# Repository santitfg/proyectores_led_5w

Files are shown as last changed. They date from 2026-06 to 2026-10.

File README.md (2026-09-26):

# redo
en el 74hc595 el pin 10 (rst ) si o si a vcc
y el pin 13 output enable va a gng si o si 

### Conector 1 — entrada de datos serie (SER)

Chip: 74HC595 (registro de desplazamiento serie-in / paralelo-out). Molex 5 pines.

| Pin | Color | Señal | GPIO ESP32 | GPIO ESP32-S3 | Descripción |
|-----|---|---|---|---|---|
| 1 | ⚫ Negro  | GND | — | — | Tierra |
| 2 | ⚪ Blanco | SRCLK / CP | `gpio23` | `gpio18` | Shift Clock (SH_CP, pin 11) / SPI2 SCLK |
| 3 | 🟢 Verde  | RCLK / PL | `gpio22` | `gpio10` | Register Clock / Latch (ST_CP, pin 12) |
| 4 | 🩶 Gris | SER  / DS | `gpio2` | `gpio4` | Serial data in (DS, pin 14) / SPI2 MOSI |
| 5 | 🔴 Rojo | VCC | — | — | Alimentación |

### Conector 2 — salida en cascada (Q7)

Conector para encadenar el `SER` (pin 14) del siguiente 74HC595 a la salida en cascada `Q7'` (pin 9) de este.

| Pin | Color | Señal | GPIO ESP32 | GPIO ESP32-S3 | Descripción |
|-----|---|---|---|---|---|
| 1 | ⚫ Negro  | GND | — | — | Tierra |
| 2 | ⚪ Blanco | SRCLK  / CP| `gpio23` | `gpio18` | Shift Clock (SH_CP, pin 11) / SPI2 SCLK |
| 3 | 🟢 Verde  | RCLK  / PL | `gpio22` | `gpio10` | Register Clock / Latch (ST_CP, pin 12) |
| 4 | 🩶 Gris | Q7 | `gpio35` | `gpio5` | Salida en cascada (Q7', pin 9) hacia el `SER` del siguiente 74HC595 |
| 5 | 🔴 Rojo | VCC | — | — | Alimentación |

estoy controlando con el 74hc595 la matriz desde las siguientes filas y columnas:
Q0 ... Q3 se conectan a los 2n2222 controlanto el gate de IRF9630
Q4 ... Q7 se conectan directo al gate IRLZ44N

# revision de laburo

PCB

IRF9630 high side y esta a up down en gate
IRLZ44N	low side y esta a pull down en gate

————

revision en protoboard 5v y señales activas de irlz44n y 2n2222 a 3.3:
IRLZ44N
gate ( pin 1) 10k a pull Down 1k a señal (vcc activa el paso de corriente)
drain ( pin 2) a gnd-terminal
source (pin 3) a GND

IRF9630
gate ( pin 1) 10k a pull up 1k a señal (gnd activa el paso de corriente)(2n2222)
drain ( pin 2) a Vout-terminal
source (pin 3) a VIN

2n2222 ( funcionamiento real es emisor a gnd y colector lado vcc)
emisor (pin 1) a GND
base (pin 2) señal ic ( via 1k Resi)
colector (pin 3) ( señal hacia irf9630 via 1k resi) vcc activa el paso de corriente)x

TODO: arreglar kicad corrigiendo los elementos mencionados (inverti pista VIN x Vout-terminal)

Fallas en el circuito funciona la mitad de puntos en modo damero
O X O X
X O X O 
O X O X
X O X O

Nomenclar correstamente las columnas y filas 
pero los v y gnd en los mismos no todos fallan de la misma manera
1: 2: 3: 4: 

Filas
q0 (pin 15) : IRF9630 1
q1 (pin 1) : IRF9630 2
q2 (pin 2) : IRF9630 3
q3 (pin 3) : IRF9630 4

Columnas
q4 (pin 4) : IRLZ44N 1
q5 (pin 5) : IRLZ44N 2
q6 (pin 6) : IRLZ44N 3
q7 (pin 7) : IRLZ44N 4

.   q4  q3  q2  q1
q3  4   3   2   1
q2  8   7   6   5
q1  12  11  10  9
q0  16  15  14  13     

funciona raro al enviar 0xFF se apagan las salidas y al 0x00 se prenden

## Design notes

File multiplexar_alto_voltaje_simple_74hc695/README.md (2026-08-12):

# Multiplexado de Matriz LED con 74HC595

Control de una matriz de LEDs de alto voltaje mediante un registro de desplazamiento 74HC595,
con MOSFETs canal N (IRFZ44N) para columnas y canal P (IRF9630) para filas.

Actualmente configurado en **2×2**, escalable a **4×4** cambiando dos constantes.

---

## Hardware

### Componentes
| Componente | Función |
|---|---|
| Arduino (cualquier) | Microcontrolador |
| 74HC595 | Registro de desplazamiento (8 bits) |
| IRFZ44N × N_COLS | MOSFET canal N → columnas (lado bajo) |
| IRF9630 × N_ROWS | MOSFET canal P → filas (lado alto) |

### Conexión 74HC595

| Arduino | Pin 74HC595 | Señal |
|---|---|---|
| D11 | 14 (DS) | Serial data |
| D13 | 11 (SCLK) | Shift clock |
| D10 | 12 (RCLK) | Latch / storage clock |
| VCC | 16 (VCC) | Alimentación |
| GND | 8 (GND) | Tierra |
| GND | 13 (OE) | Output enable (activo bajo) |
| VCC | 10 (SRCLR) | Clear (activo bajo, mantener HIGH) |

Las salidas Q0–Q(N_COLS-1) van a las compuertas de los IRFZ44N (columnas)
y Q(N_COLS)–Q(N_COLS+N_ROWS-1) van a las compuertas de los IRF9630 (filas).

---

## Bit layout del registro

```
2×2:  bit3  bit2  bit1  bit0
       r1    r0    c1    c0

4×4:  bit7  bit6  bit5  bit4  bit3  bit2  bit1  bit0
       r3    r2    r1    r0    c3    c2    c1    c0
```

- **Columnas (IRFZ44N canal N):** `1` = activo (MOSFET conduce)
- **Filas (IRF9630 canal P):** lógica `1` = activo, pero el firmware invierte automáticamente al enviar al 595 (`~rowMask`) porque el gate del P-channel requiere bajo para conducir

---

## Demo

El `loop()` habilita una compuerta más cada **200 ms** en orden acumulativo:

```
idx=0  c0           → col 0 habilitada
idx=1  c0 c1        → cols 0 y 1 habilitadas
idx=2  c0 c1 r0     → cols 0-1 + fila 0 habilitada
idx=3  c0 c1 r0 r1  → todo habilitado → reset
```

Salida Serial (115200 baud):
```
 0  | logic: 0000 0001  | phys: 0000 1101  | cols=0b1    rows=0b0
 1  | logic: 0000 0011  | phys: 0000 1111  | cols=0b11   rows=0b0
 2  | logic: 0000 0101  | phys: 0000 0101  | cols=0b1    rows=0b1
 3  | logic: 0000 0111  | phys: 0000 0111  | cols=0b11   rows=0b11
```
- **logic**: estado lógico (1 = activo, sin importar polaridad)
- **phys**: byte real enviado al 595 (filas invertidas para P-channel)

---

## Escalar a 4×4

Solo cambiar estas dos líneas en el sketch:

```cpp
const uint8_t N_COLS = 4;
const uint8_t N_ROWS = 4;
```

No hay más cambios necesarios. El cálculo de máscaras y el bit packing se adaptan automáticamente.

---

## Control individual de LEDs

```cpp
setLED(col, row, true);   // encender LED en columna col, fila row
setLED(col, row, false);  // apagar
```

> **Nota ghosting:** activar simultáneamente múltiples columnas y filas ilumina
> LEDs no deseados (ej: encender (c0,r0) y (c1,r1) también activa (c0,r1) y (c1,r0)).
> Ver la sección de multiplexing por fila al final del sketch para evitarlo.

---

## Multiplexing por fila (sin ghosting)

Para control de LEDs individuales sin ghosting, usar un framebuffer por fila:

```cpp
uint8_t framebuffer[N_ROWS] = { 0b01, 0b10 };  // fila0: col0 ON, fila1: col1 ON

for (uint8_t r = 0; r < N_ROWS; r++) {
    rowMask = (1 << r);
    colMask = framebuffer[r];
    sendToShiftReg();
    delayMicroseconds(500);   // tiempo de encendido por fila
    colMask = 0; rowMask = 0;
    sendToShiftReg();         // apagar entre filas evita ghosting
}
```

El ojo percibe todas las filas encendidas si el ciclo completo dura < ~20 ms.

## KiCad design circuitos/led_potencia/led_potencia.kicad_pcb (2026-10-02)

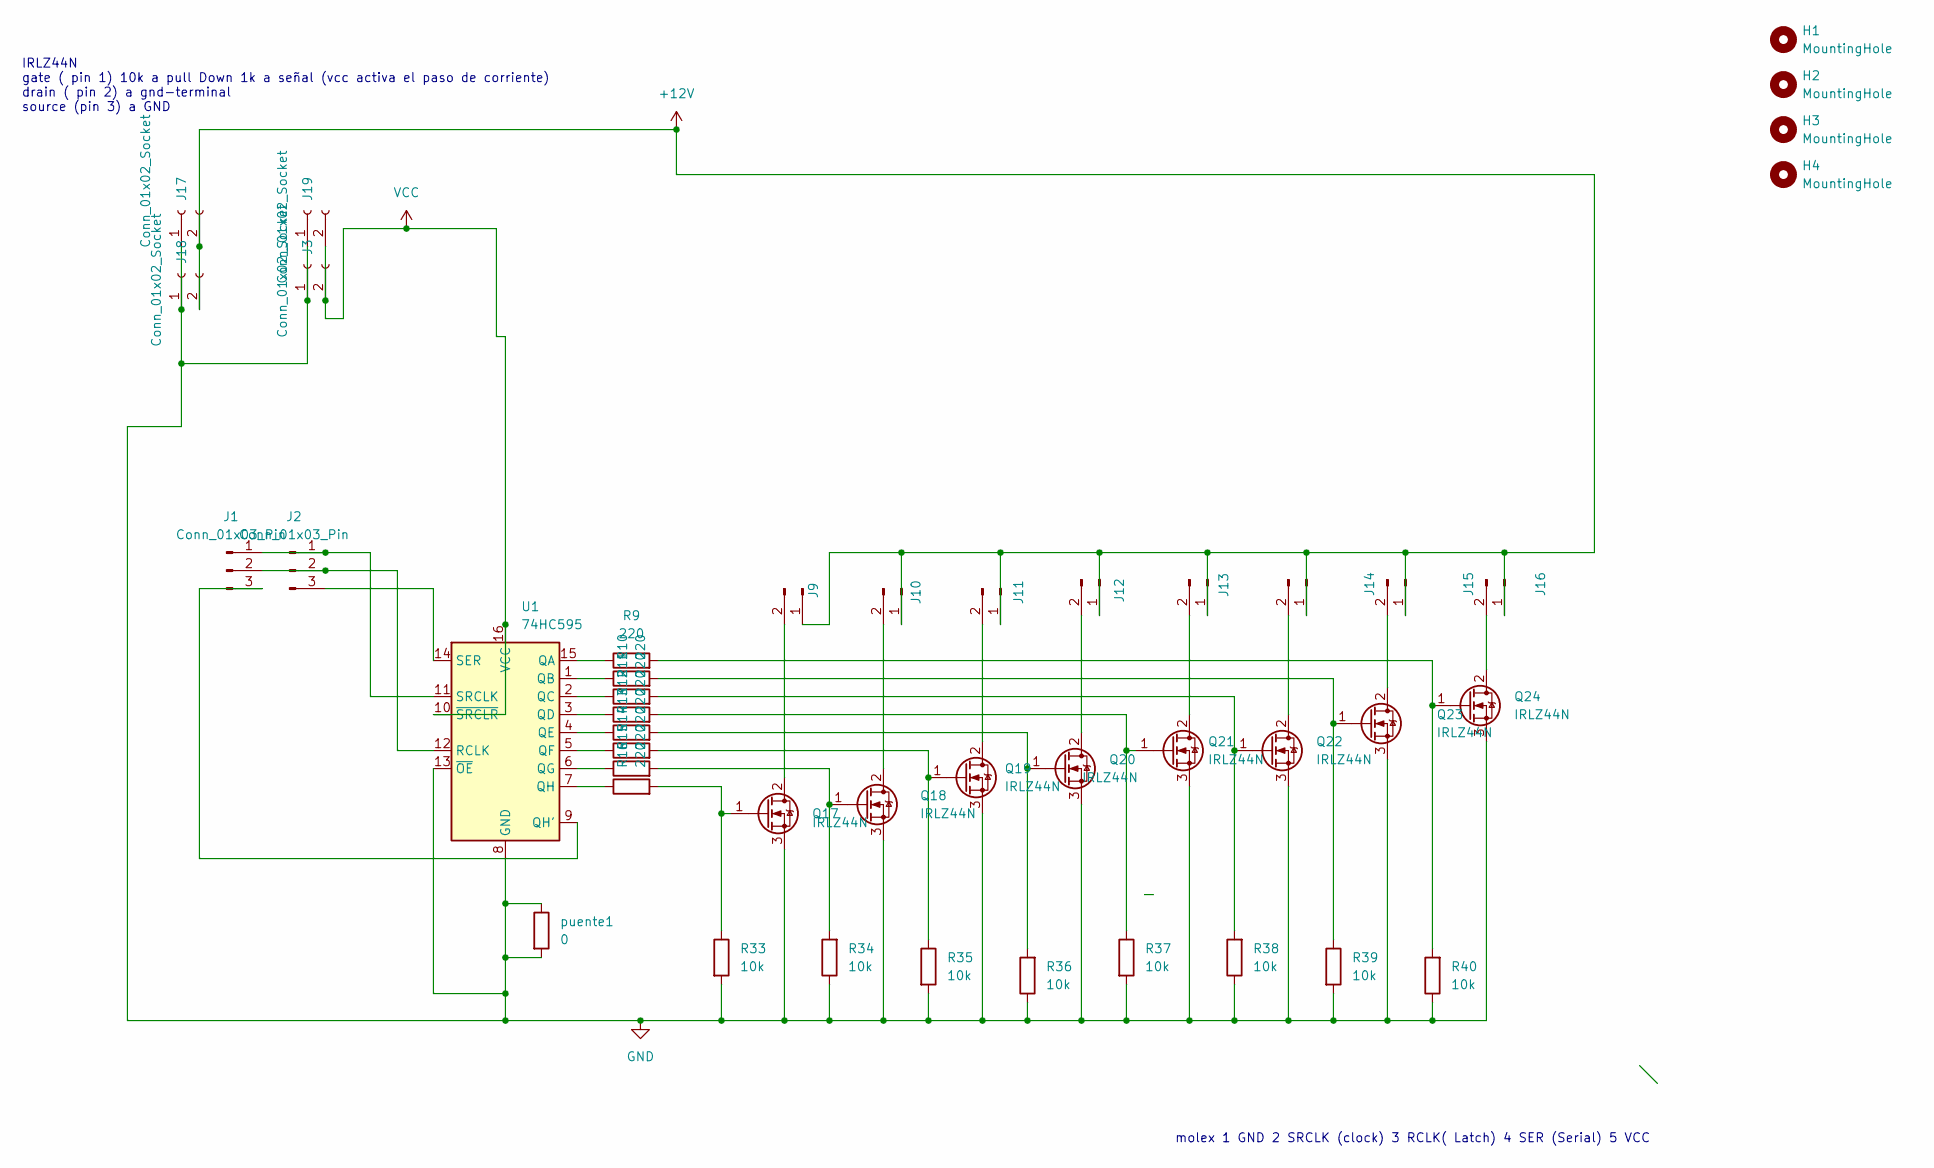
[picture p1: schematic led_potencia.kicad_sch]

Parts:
H1, H2, H3, H4: MountingHole; MountingHole_2.2mm_M2_DIN965_Pad
J1, J2: Conn_01x03_Pin; Molex_KK-254_AE-6410-03A_1x03_P2.54mm_Vertical
J3, J17, J18, J19: Conn_01x02_Socket; Molex_KK-254_AE-6410-02A_1x02_P2.54mm_Vertical
J9, J10, J11, J12, J13, J14, J15, J16: Conn_01x02_Pin; Molex_KK-254_AE-6410-02A_1x02_P2.54mm_Vertical
Q17, Q18, Q19, Q20, Q21, Q22, Q23, Q24: IRLZ44N; TO-220-3_Vertical
R9, R10, R11, R12, R13, R14, R15, R16: 220; R_Axial_DIN0204_L3.6mm_D1.6mm_P7.62mm_Horizontal
R33, R34, R35, R36, R37, R38, R39, R40: 10k; R_Axial_DIN0204_L3.6mm_D1.6mm_P7.62mm_Horizontal
U1: 74HC595; DIP-16_W7.62mm_Socket_LongPads
puente1: 0; R_Axial_DIN0204_L3.6mm_D1.6mm_P7.62mm_Horizontal

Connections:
+12V: J9.1, J10.1, J11.1, J12.1, J13.1, J14.1, J15.1, J16.1, J17.2, J18.2
GND: J3.1, J17.1, J18.1, J19.1, Q17.3 (S), Q18.3 (S), Q19.3 (S), Q20.3 (S), Q21.3 (S), Q22.3 (S), Q23.3 (S), Q24.3 (S), R33.2, R34.1, R35.2, R36.1, R37.2, R38.1, R39.2, R40.1, U1.8 (GND), U1.13 (~OE), puente1.1, puente1.2
unnamed: J1.1, J2.1, U1.11 (SRCLK)
unnamed: J1.2, J2.2, U1.12 (RCLK)
unnamed: J1.3, U1.9 (QH')
unnamed: J2.3, U1.14 (SER)
unnamed: J9.2, Q17.2 (D)
unnamed: J10.2, Q18.2 (D)
unnamed: J11.2, Q19.2 (D)
unnamed: J12.2, Q20.2 (D)
unnamed: J13.2, Q21.2 (D)
unnamed: J14.2, Q22.2 (D)
unnamed: J15.2, Q23.2 (D)
unnamed: J16.2, Q24.2 (D)
unnamed: Q17.1 (G), R16.2, R33.1
unnamed: Q18.1 (G), R15.2, R34.2
unnamed: Q19.1 (G), R14.2, R35.1
unnamed: Q20.1 (G), R13.2, R36.2
unnamed: Q21.1 (G), R12.2, R37.1
unnamed: Q22.1 (G), R11.2, R38.2
unnamed: Q23.1 (G), R10.2, R39.1
unnamed: Q24.1 (G), R9.2, R40.2
unnamed: R9.1, U1.15 (QA)
unnamed: R10.1, U1.1 (QB)
unnamed: R11.1, U1.2 (QC)
unnamed: R12.1, U1.3 (QD)
unnamed: R13.1, U1.4 (QE)
unnamed: R14.1, U1.5 (QF)
unnamed: R15.1, U1.6 (QG)
unnamed: R16.1, U1.7 (QH)
VCC: J3.2, J19.2, U1.10 (~SRCLR), U1.16 (VCC)

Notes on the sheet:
IRLZ44N gate ( pin 1) 10k a pull Down 1k a señal (vcc activa el paso de corriente) drain ( pin 2) a gnd-terminal source (pin 3) a GND
molex 1 GND 2 SRCLK (clock) 3 RCLK( Latch) 4 SER (Serial) 5 VCC

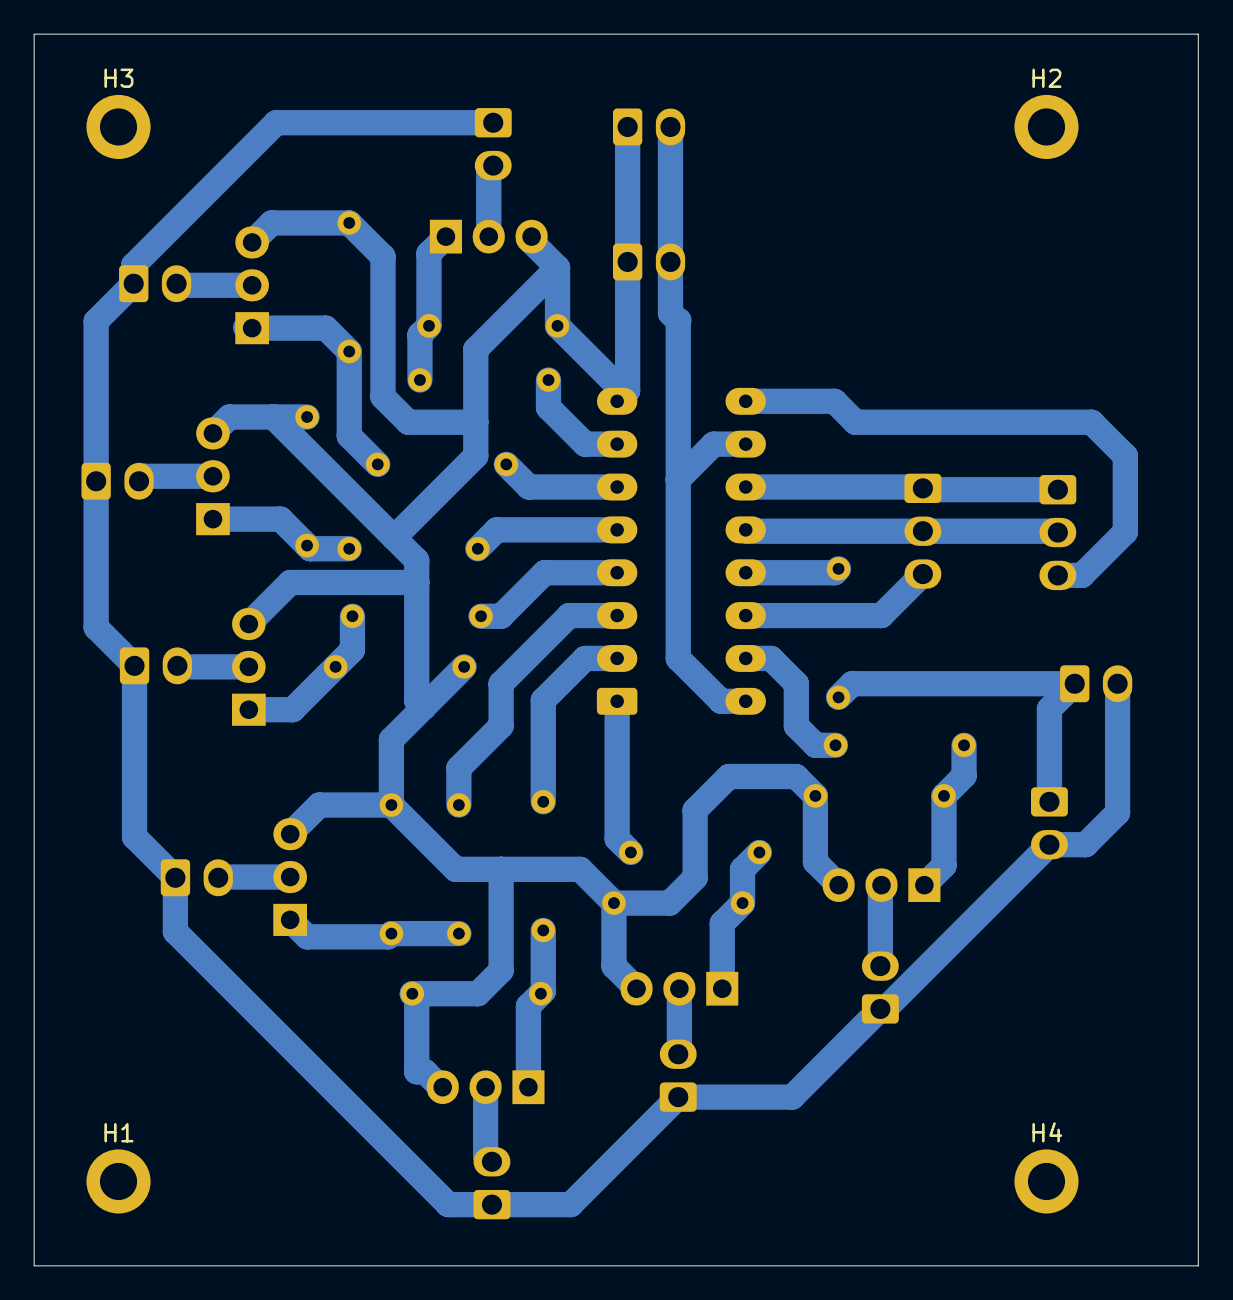
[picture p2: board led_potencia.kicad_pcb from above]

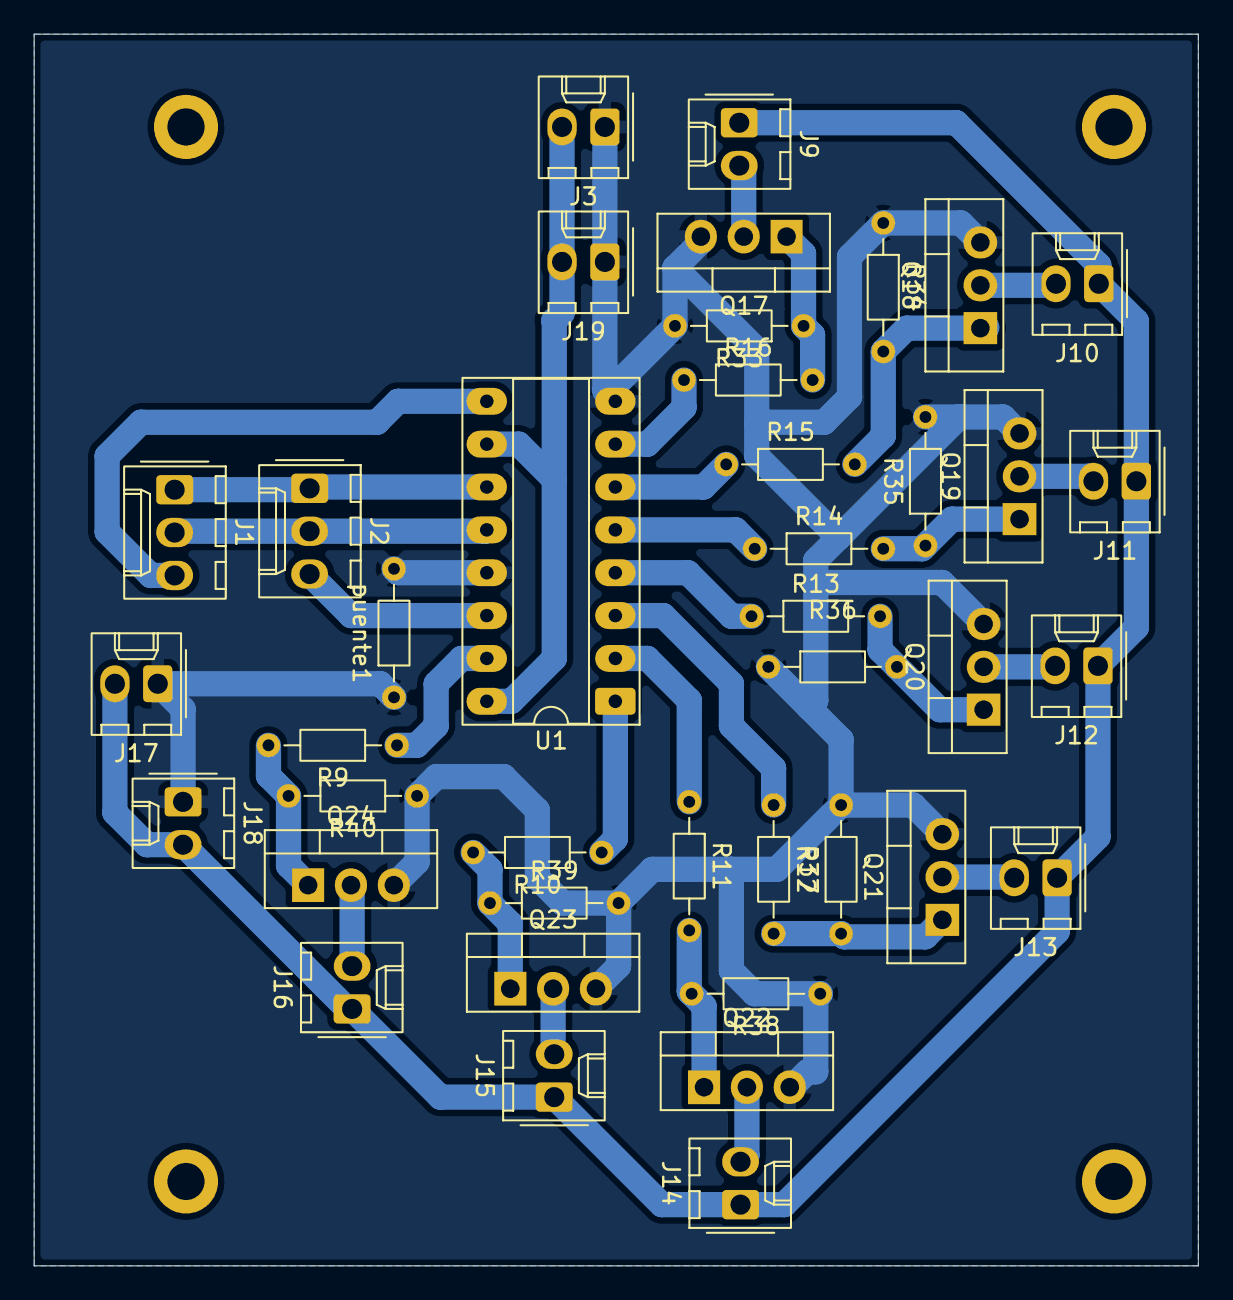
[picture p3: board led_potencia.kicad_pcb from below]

Board: 2 copper layers, 69.0 x 73.0 mm, 44 parts (40 on the bottom side), 31 nets.

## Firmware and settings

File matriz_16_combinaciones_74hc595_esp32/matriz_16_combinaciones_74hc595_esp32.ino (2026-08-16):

/*
 * Test de hardware — barrido de las 16 combinaciones fila×columna — ESP32 / ESP32-S3
 *
 * Recorre las 4 filas × 4 columnas (16 combinaciones), encendiendo una
 * fila y una columna a la vez para verificar cada cruce de la matriz:
 *   - Q0..Q3 → base de 2N2222 → gate de IRF9630 (canal P, filas, lado alto)
 *   - Q4..Q7 → gate directo de IRLZ44N (canal N, columnas, lado bajo)
 *
 * En ambos casos la señal es ALTA para habilitar el paso de corriente:
 *   - Filas (IRF9630, high side): el 2N2222 invierte la señal, por lo
 *     que un "1" en Q0..Q3 satura el 2N2222, que a su vez tira el gate
 *     del IRF9630 a GND y lo enciende.
 *   - Columnas (IRLZ44N, low side): un "1" en Q4..Q7 lleva el gate
 *     directo a VCC y lo enciende.
 *
 * ── Conexión 74HC595 (Conector 1, ver README.md del proyecto) ──
 *              Señal        ESP32     ESP32-S3
 *   Pin 2   SRCLK / CP   gpio23      gpio18   (Shift Clock, pata 11)
 *   Pin 3   RCLK  / PL   gpio22      gpio10   (Latch,       pata 12)
 *   Pin 4   SER   / DS   gpio2       gpio4    (Data in,     pata 14)
 *   Pin 1   GND          —           —
 *   Pin 5   VCC          —           —
 *
 * OE (pata 13) a GND y SRCLR (pata 10) a VCC (fijo, no controlado
 * desde el ESP32).
 *
 * ── Conector 2 (cascada) ────────────────────────────────────────
 *   Pin 4   Q7    gpio35      gpio5    (Q7', pata 9, hacia SER del siguiente 595)
 *   Se lee como entrada para capturar el bit que sale por cascada.
 *
 * El target (ESP32 clásico vs ESP32-S3) se detecta automáticamente
 * con CONFIG_IDF_TARGET_ESP32S3, definido por el core de Arduino.
 */

#if CONFIG_IDF_TARGET_ESP32S3
  #define PIN_SRCLK 18   // Shift clock
  #define PIN_RCLK  10   // Latch
  #define PIN_SER    4   // Serial data in
  #define PIN_Q7     5   // Cascade out (Q7')
#else
  #define PIN_SRCLK 23   // Shift clock
  #define PIN_RCLK  22   // Latch
  #define PIN_SER    2   // Serial data in
  #define PIN_Q7    35   // Cascade out (Q7')
#endif

// Q0..Q3 → filas (2N2222 + IRF9630) | Q4..Q7 → columnas (IRLZ44N directo)
#define N_ROWS 4
#define N_COLS 4

// ────────────────────────────────────────────────────────────────
// Envía un byte al 74HC595 y actualiza el latch
// ────────────────────────────────────────────────────────────────
void sendToShiftReg(uint8_t value) {
  digitalWrite(PIN_RCLK, LOW);
  shiftOut(PIN_SER, PIN_SRCLK, LSBFIRST, value);
  digitalWrite(PIN_RCLK, HIGH);
}

void setup() {
  Serial.begin(115200);
  pinMode(PIN_SER,   OUTPUT);
  pinMode(PIN_SRCLK, OUTPUT);
  pinMode(PIN_RCLK,  OUTPUT);
  pinMode(PIN_Q7,    INPUT);   // Q7' de cascada, gpio35/gpio5 sólo lectura

  sendToShiftReg(0x00);  // todas las salidas apagadas

  Serial.println(F("== Test hardware: barrido de las 16 combinaciones fila x columna =="));
}

void loop() {
  for (uint8_t row = 0; row < N_ROWS; row++) {
    for (uint8_t col = 0; col < N_COLS; col++) {
      uint8_t out = (uint8_t)(1 << row) | (uint8_t)(1 << (N_ROWS + col));
      sendToShiftReg(out);

      Serial.print(F("FILA "));
      Serial.print(row);
      Serial.print(F(" / COLUMNA "));
      Serial.print(col);
      Serial.print(F(" | byte=0x"));
      Serial.print(out, HEX);
      Serial.print(F(" | Q7' cascada="));
      Serial.println(digitalRead(PIN_Q7));

      delay(500);
    }
  }
}

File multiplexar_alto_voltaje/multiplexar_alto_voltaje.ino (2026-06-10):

// Columnas Mosfet Canal N - IRFZ44N _ lado bajo de cambio
// pata en alto permite el paso de correinte
int pinesColumnas[2] = { 3, 4 };

// Filas Canal P - IRF9630 _ lado alto de cambio
// pata en bajo permite el paso de correinte
int pinesFilas[2] = { 8, 9 };

void setup() {
  // put your setup code here, to run once:
  for (int i = 0; i < sizeof(pinesColumnas) / sizeof(pinesColumnas[0]); i++) {
    pinMode(pinesColumnas[i], OUTPUT);
  }
  for (int i = 0; i < sizeof(pinesFilas) / sizeof(pinesFilas[0]); i++) {
    pinMode(pinesFilas[i], OUTPUT);
  }
}

void loop() {
  // put your main code here, to run repeatedly:
}

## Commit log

2026-06-16 circuito wip
    [led_potencia.kicad_pcb, led_potencia.kicad_sch]
2026-06-16 mejorando array
    [led_potencia.kicad_pcb, led_potencia.kicad_sch]
2026-06-26 logica funcionan pasando a pcb
    [led_potencia.kicad_sch]
2026-06-28 sumando cambios
    [led_potencia.kicad_pcb, led_potencia.kicad_sch]
2026-06-29 armando grilla PCB
    [led_potencia.kicad_pcb, led_potencia.kicad_sch]
2026-06-29 circuito pre finalizado, retestear en proto e imprimir
    [led_potencia.kicad_pcb, led_potencia.kicad_sch]
2026-06-30 in out añadidos
    [led_potencia.kicad_pcb, led_potencia.kicad_sch]
2026-06-30 variante de ruteo v2 contrastar?
    [led_potencia.kicad_pcb]
2026-06-30 obse nomai v3 de ruteo (podria achicarse mucho mas pero no es sano
    [led_potencia.kicad_pcb]
2026-07-15 achicando marggen por seguridad
    [led_potencia.kicad_pcb]
2026-07-17 relleno gnd
    [led_potencia.kicad_pcb]
2026-07-24 cambios en ruteo
    [led_potencia.kicad_pcb]
2026-08-12 script de testeo all on-off
    [led_potencia.kicad_pcb]
2026-08-13 nota para correccion
    [led_potencia.kicad_pcb]
2026-08-16 problemas tecnicos prueba y notas sobre circuito correcto sobre proto
    [secuencia_74hc595_esp32.ino]
2026-08-16 todo: ruteo y revision de pcb ya impreso en funcion de porque no prende y apaga
    [led_potencia.kicad_sch]
2026-09-28 cambio irlz44n x8x2 subida pre simplificar
    [led_potencia.kicad_pcb, led_potencia.kicad_sch]
2026-09-28 simplificacion juegos de 1 ic x pcb 8 irlzn
    [led_potencia.kicad_pcb, led_potencia.kicad_sch]
2026-10-02 cambiando resistencias
    [led_potencia.kicad_sch]
2026-10-02 ruteo : pre inversion
    [led_potencia.kicad_pcb, led_potencia.kicad_sch]
